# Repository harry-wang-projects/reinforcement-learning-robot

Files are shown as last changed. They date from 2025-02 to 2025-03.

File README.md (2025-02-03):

Learning robot project

This robot navigates around a room using a rotating ToF sensor. It aims to cover a wide area without crashing into anything. 

Unlike regular robots, this robot will "learn" how to avoid obstacles using a neural network. It will be given ToF sensor readings and will be asked to output the motor controls. In addition, I will install a bumper to detect when the robot crashes (alternatively, I could count ToF sensor readings under 10 cm as a "crash" ). The robot will be given a score system, and will lose points if the robot does not move or if it crashes.

If successful enough, the robot can be used to map out rooms.

Inputs:
- ToF sensor reading array
- Whether or not the robot crashed
Outputs:
- Motor 1 speed/direction
- Motor 2 speed/direction

Rules:
- Not moving will cause the robot to lose points
- Moving straight will give more points than turning. The higher the speed, the more points.
- Crashing will cause the robot to lose many points
- Going backwards will deduct points
- Staying in the same area for very long will deduct points
- Bonus: The robot could be rewarded for facing certain directions/going to certain points.
- Bonus: An IR beacon can be placed such that if the robot receives an IR signal, it loses points.

Phases of this project:
1. Creating a robot with a functional ToF sensor and bumper that can be remotely driven
2. Training a neural network that can allow the robot to drive without crashing
3. Improving the neural network and the hardware (e.g. adding sensors to the back, adding an IR beacon that the robot should follow/avoid)
4. Using more advanced sensors (e.g. Lidar, camera)

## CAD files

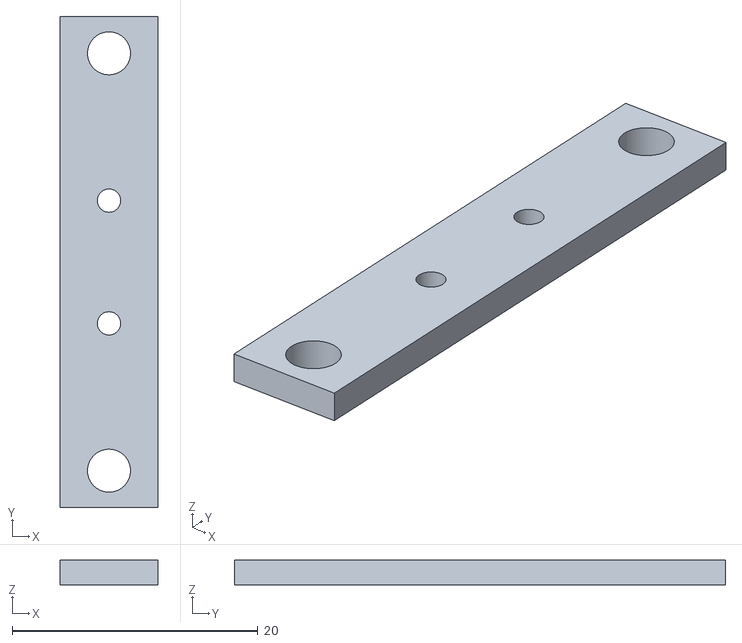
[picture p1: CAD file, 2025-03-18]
objects/switchh2.stl
8.00 x 40.0 x 2.00

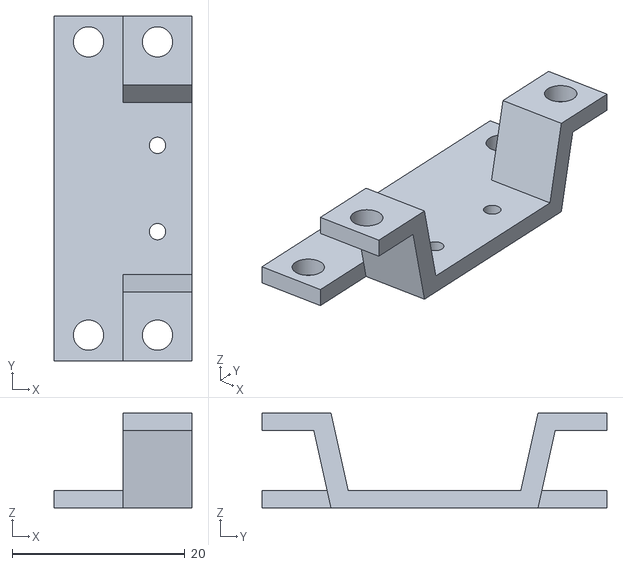
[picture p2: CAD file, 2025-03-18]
objects/switchh1.stl
16.0 x 40.0 x 11.0

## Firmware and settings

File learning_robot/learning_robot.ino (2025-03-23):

//main code for learning robot

#include <WiFi.h>
#include "VL53L1X.h"


//blinking
int doiblink = 0;
int blinktime = 0;

void quickblink(){
  digitalWrite(23, HIGH);
  doiblink = 1;
  blinktime = millis() + 200;
}

//sensor
VL53L1X sensor;

void sensor_init(VL53L1X::DistanceMode range_mode, bool high_speed) {
  Wire.begin();
  sensor.setTimeout(500);
  sensor.init();
  sensor.setDistanceMode(range_mode);  
  int budget = high_speed ? 33000 : 140000;
  sensor.setMeasurementTimingBudget(budget);
}

//motors
int aone = 2;
int atwo = 4;
int bone = 5;
int btwo = 15;

//motor speeds
int atarget = 0;
int btarget = 0;
int acurrent = 0;
int bcurrent = 0;

void drive_motors(int aspeed, int bspeed)
{
  if(aspeed > 0){
    analogWrite(aone, aspeed);
    analogWrite(atwo, 0);
  }else if(aspeed < 0){
    analogWrite(aone, 0);
    analogWrite(atwo, -aspeed);
  }else{
    analogWrite(aone, 0);
    analogWrite(atwo, 0);
  }
  if(bspeed > 0){
    analogWrite(bone, bspeed);
    analogWrite(btwo, 0);
  }else if(bspeed < 0){
    analogWrite(bone, 0);
    analogWrite(btwo, -bspeed);
  }else{
    analogWrite(bone, 0);
    analogWrite(btwo, 0);
  }
}

int lastmod_millis = 0;
void change_speed()
{
  int achange = atarget - acurrent;
  if(achange > 30){
    acurrent += 30;
  }else if (achange < -30){
    acurrent -= 30;
  }else{
    acurrent += achange;
  }
  int bchange = btarget - bcurrent;
  if(bchange > 30){
    bcurrent += 30;
  }else if (bchange < -30){
    bcurrent -= 30;
  }else{
    bcurrent += bchange;
  }
  Serial.printf("%d %d\n", acurrent, bcurrent);
  if(achange != 0 || bchange != 0)
    drive_motors(acurrent, bcurrent);
}

void set_speed(int newa, int newb)
{
  atarget = newa;
  btarget = newb;
}

//servo

float maxduty = 8200.0;
float minduty = 1800.0;
float angle2servo(int angle){
  return (float)angle * (maxduty - minduty) / 180.0 + minduty;
}

int angle = 0;

//server
NetworkServer server(80);

void setup() {
  pinMode(23, OUTPUT);
  digitalWrite(23, HIGH);
  delay(500);
  digitalWrite(23, LOW);
  delay(500);

  pinMode(aone, OUTPUT);
  pinMode(atwo, OUTPUT);
  pinMode(bone, OUTPUT);
  pinMode(btwo, OUTPUT);
  analogWrite(aone, LOW);
  analogWrite(atwo, LOW);
  analogWrite(bone, LOW);
  analogWrite(btwo, LOW);

  ledcAttach(18, 50, 16); // channel 1, 50 Hz, 16-bit width
  ledcWrite(18, 3 * 770 + 1638); 

  Serial.begin(115200);

  delay(10);

  sensor_init(VL53L1X::Long, false);   

  // We start by connecting to a WiFi network

  Serial.println();
  Serial.println();
  //Serial.print("Connecting to ");
  //Serial.println(ssid);

  /*
  WiFi.begin(ssid, password);

  while (WiFi.status() != WL_CONNECTED) {
    delay(500);
    Serial.print(".");
  }
  */
  WiFi.softAP("harry2", NULL);

  Serial.println("");
  Serial.println("WiFi connected.");
  Serial.println("IP address: ");
  Serial.println(WiFi.localIP());

  server.begin();
  digitalWrite(23, HIGH);
  delay(500);
  digitalWrite(23, LOW);
  delay(500);
}

int last_check = 0;
//time for each small scan
int wait_milliseconds = 20;

//(180/5)+1
int distances[37] = {0};

//0 = increasing, 1 = decreasing
int spin_direction = 0;

void loop() {
  //blinking stuff
  if (doiblink == 1 && millis() >= blinktime){
    doiblink = 0;
    digitalWrite(23, LOW);
  }

  //motor speed changing
  if(millis() >= lastmod_millis + 100){
    change_speed();
    lastmod_millis = millis();
  }

  
  if(millis() - last_check > wait_milliseconds){
    last_check = millis();

    int dist = sensor.readRangeSingleMillimeters();
    distances[angle / 5] = dist;

    if(spin_direction == 0){
      angle += 5;
      if(angle == 180){
        spin_direction = 1;
      }
    }else{
      angle -= 5;
      if(angle == 0){
        spin_direction = 0;
      }
    }
    ledcWrite(18, (int)angle2servo(angle)); 
  }
  

  NetworkClient client = server.accept();  // listen for incoming clients

  if (client) {                     // if you get a client,
    Serial.println("New Client.");  // print a message out the serial port
    String currentLine = "";        // make a String to hold incoming data from the client
    while (client.connected()) {    // loop while the client's connected
      if (client.available()) {     // if there's bytes to read from the client,
        char c = client.read();     // read a byte, then
        Serial.write(c);            // print it out the serial monitor
        if (c == '\n') {            // if the byte is a newline character

          // if the current line is blank, you got two newline characters in a row.
          // that's the end of the client HTTP request, so send a response:
          if (currentLine.length() == 0) {
            // HTTP headers always start with a response code (e.g. HTTP/1.1 200 OK)
            // and a content-type so the client knows what's coming, then a blank line:
            client.println("HTTP/1.1 200 OK");
            client.println("Content-type:text/html");
            client.println();

            // the content of the HTTP response follows the header:
            // print radar scanning data
            
            for(int i = 0; i < 37; i++){
              client.print(distances[i]);
              client.print(" ");
            }
            client.println();
            
            // The HTTP response ends with another blank line:
            client.println();
            // break out of the while loop:
            break;
          } else {  // if you got a newline, then clear currentLine:
            currentLine = "";
          }
        } else if (c != '\r') {  // if you got anything else but a carriage return character,
          currentLine += c;      // add it to the end of the currentLine
        }

        int dutycycle = 150;
        // Check to see if the client request was "GET /H" or "GET /L":
        if (currentLine.endsWith("GET /Q")) {
          set_speed(0, dutycycle);
        }
        if (currentLine.endsWith("GET /W")) {
          set_speed(dutycycle, dutycycle);  
        }
        if (currentLine.endsWith("GET /E")) {
          set_speed(dutycycle, 0);
        }
        if (currentLine.endsWith("GET /A")) {
          set_speed(-dutycycle, dutycycle);
        }
        if (currentLine.endsWith("GET /S")) {
          set_speed(0, 0);
        }
        if (currentLine.endsWith("GET /D")) {
          set_speed(dutycycle, -dutycycle);
        }
        if (currentLine.endsWith("GET /Z")) {
          set_speed(0, -dutycycle);
        }
        if (currentLine.endsWith("GET /X")) {
          set_speed(-dutycycle, -dutycycle);
        }
        if (currentLine.endsWith("GET /C")) {
          set_speed(-dutycycle, 0);
        }
      }
      quickblink();
    }
    // close the connection:
    client.stop();
    Serial.println("Client Disconnected.");
  }

}

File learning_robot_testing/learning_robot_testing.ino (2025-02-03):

int aone = 2;
int atwo = 4;
int bone = 5;
int btwo = 15;

void setup() {
  // put your setup code here, to run once:
  pinMode(aone, OUTPUT);
  pinMode(atwo, OUTPUT);
  pinMode(bone, OUTPUT);
  pinMode(btwo, OUTPUT);
  ledcAttach(18, 50, 16); // channel 1, 50 Hz, 16-bit width
  ledcWrite(18, 3 * 770 + 1638); 
}

void loop() {
  // put your main code here, to run repeatedly:
  digitalWrite(aone, HIGH);
  digitalWrite(atwo, LOW);
  digitalWrite(bone, HIGH);
  digitalWrite(btwo, LOW);
  ledcAttach(18, 50, 16); // channel 1, 50 Hz, 16-bit width
  ledcWrite(18, 2000); 
  delay(1000);
  digitalWrite(aone, LOW);
  digitalWrite(atwo, LOW);
  digitalWrite(bone, LOW);
  digitalWrite(btwo, LOW);
  ledcAttach(18, 50, 16); // channel 1, 50 Hz, 16-bit width
  ledcWrite(18, 5000); 
  delay(1000);
  digitalWrite(aone, LOW);
  digitalWrite(atwo, HIGH);
  digitalWrite(bone, LOW);
  digitalWrite(btwo, HIGH);
  ledcAttach(18, 50, 16); // channel 1, 50 Hz, 16-bit width
  ledcWrite(18, 7500); 
  delay(1000);
  digitalWrite(aone, LOW);
  digitalWrite(atwo, LOW);
  digitalWrite(bone, LOW);
  digitalWrite(btwo, LOW);
  ledcAttach(18, 50, 16); // channel 1, 50 Hz, 16-bit width
  ledcWrite(18, 5000); 
  delay(1000);
}

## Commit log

2025-02-03 added sensor displaying
2025-03-11 added tester for motors
2025-03-11 bug fixed. digital and analog write need to be consistent.
    [learning_robot_drivetest.ino, learning_robot_motortest.ino]
2025-03-12 added acceleration. works quite well with 470 uf capacitor now.
2025-03-18 added 3d objects for front sensor holder
    [switchh1.stl, switchh2.stl]
2025-03-23 combined driving with radar. Doesn't work on battery.
    [learning_robot.ino]
2025-03-26 finally got mountaincar working
2025-03-26 ai-generated cartpole kinda works, continuous mountain car works
